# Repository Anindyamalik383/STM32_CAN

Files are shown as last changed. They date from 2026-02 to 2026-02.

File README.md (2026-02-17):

# STM32_CAN
STM32F411CEU6( Black Pill) with a CAN controller IC integrated, enabling regular CAN communications to be done.
This is done by interfacing, and a  CAN TransReceiver IC, the one used here is ATA6561-GBQW-N (Atmel IC 
PA12 and PA13 are used for interfacing with the CAN Transreceiver IC

PCB DESIGN


3D View:



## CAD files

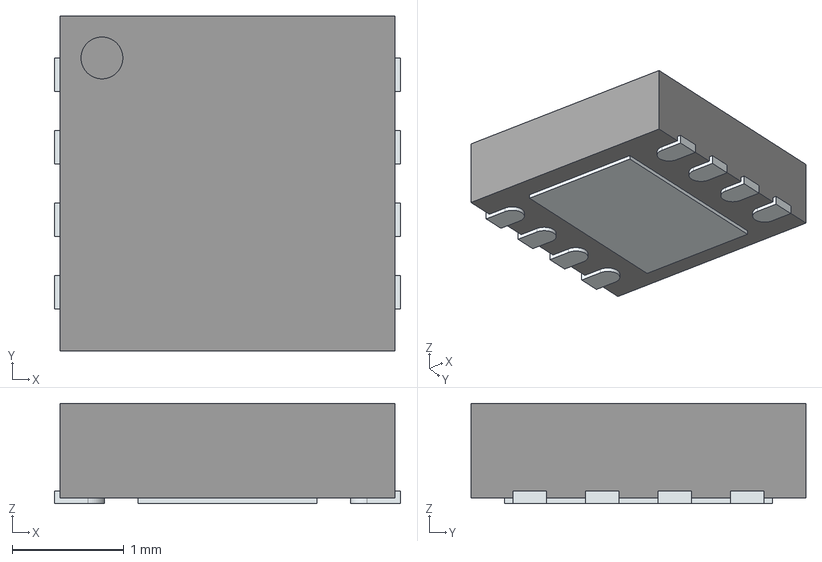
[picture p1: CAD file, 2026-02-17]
EXT_LIB/ATA6561-GBQW-N/ATA6561-GBQW-N.stp
3.10 x 3.00 x 0.9 mm
ThermalPin
PinsArrayLR

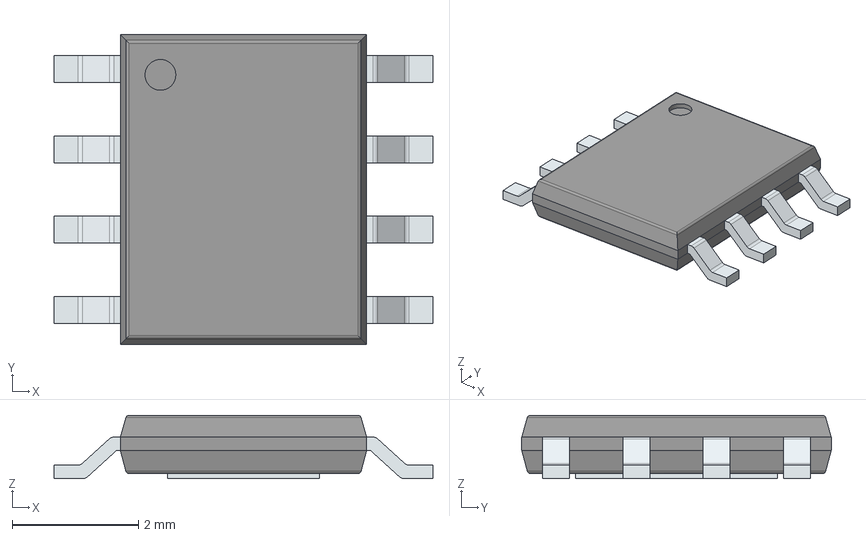
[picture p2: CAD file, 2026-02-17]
EXT_LIB/BD50GA3WEFJ-E2/3D/BD50GA3WEFJ-E2.stp
6.00 x 4.90 x 1.00 mm
PinsArrayLR
ThermalPad

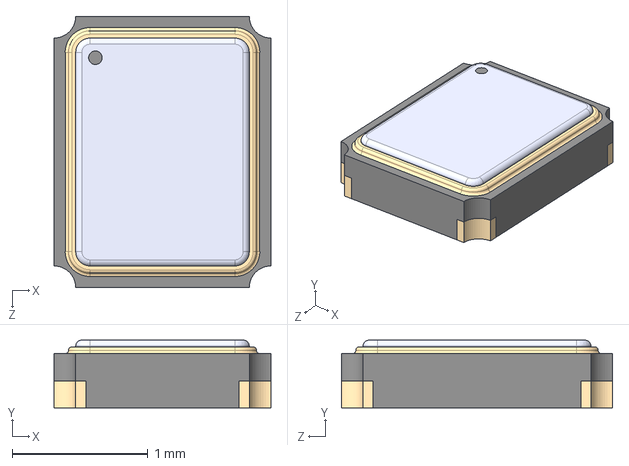
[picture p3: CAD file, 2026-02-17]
EXT_LIB/FA-128_25.0000MF10Z-AC/3D/FA-128_25.0000MF10Z-AC.stp
1.60 x 0.5 x 2.00 mm

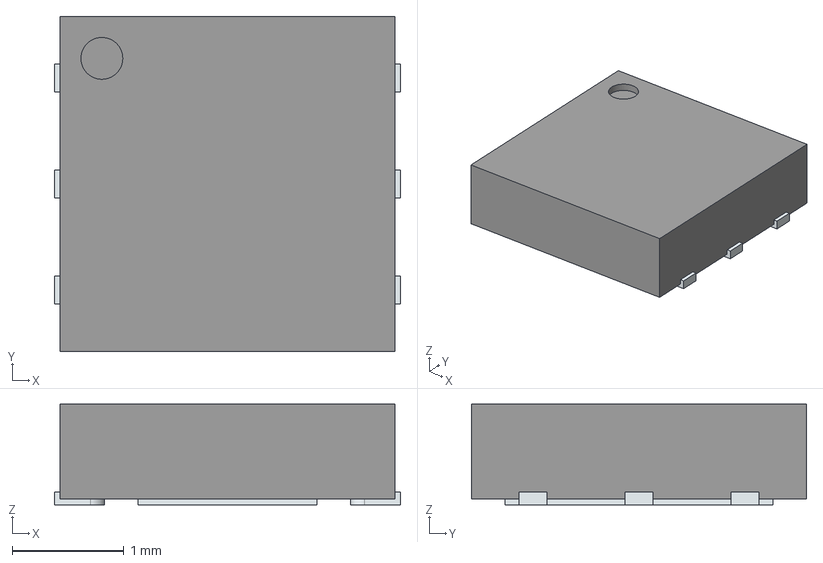
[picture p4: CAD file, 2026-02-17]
EXT_LIB/LDO40LPU33RY/3D/LDO40LPU33RY.stp
3.10 x 3.00 x 0.9 mm
ThermalPin
PinsArrayLR

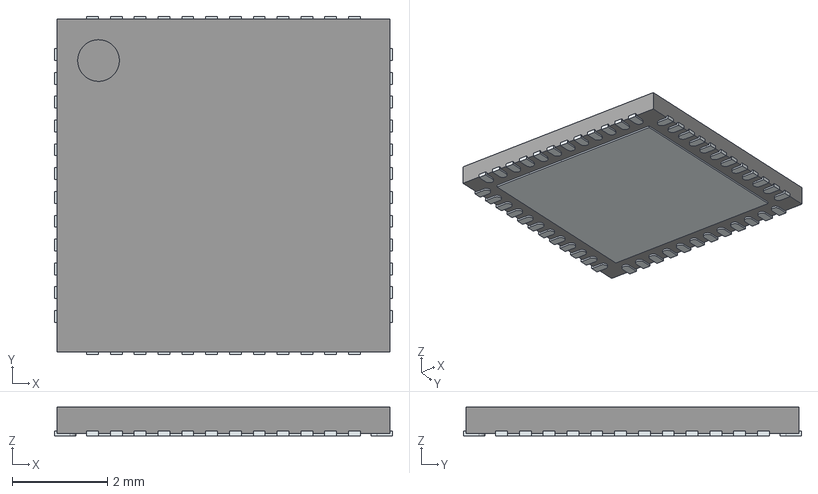
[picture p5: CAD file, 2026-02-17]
EXT_LIB/STM32F411CEU6/STM32F411CEU6.stp
7.10 x 7.10 x 0.6 mm
ThermalPin
PinsArrayLR
PinsArrayTB

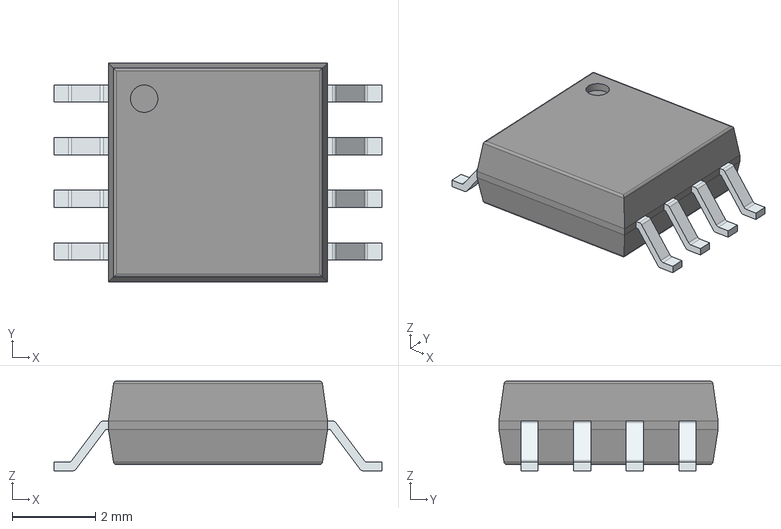
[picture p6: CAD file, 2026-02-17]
EXT_LIB/W25Q32JVSSIQ/W25Q32JVSSIQ/3D/W25Q32JVSSIQ.stp
7.90 x 5.28 x 2.16 mm
PinsArrayLR

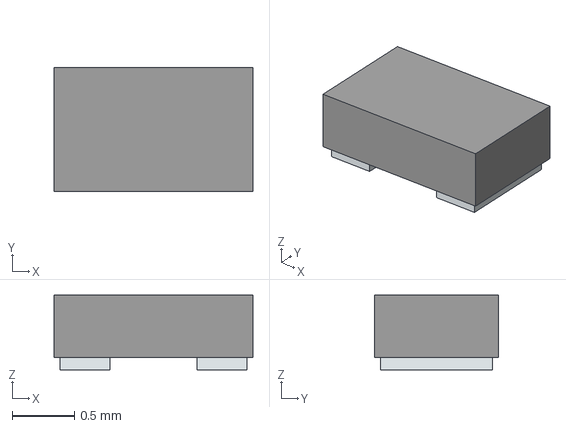
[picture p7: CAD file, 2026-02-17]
EXT_LIB/830107088501/3D/830107088501.stp
1.60 x 1.00 x 0.6 mm
Pins

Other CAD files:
EXT_LIB/W25Q32JVSSIQ/W25Q32JVSSIQ/Allegro/soic127p790x216-8n.psm
EXT_LIB/W25Q32JVSSIQ/W25Q32JVSSIQ/DEHDL/w25q32jvssiq/chips/chips.prt

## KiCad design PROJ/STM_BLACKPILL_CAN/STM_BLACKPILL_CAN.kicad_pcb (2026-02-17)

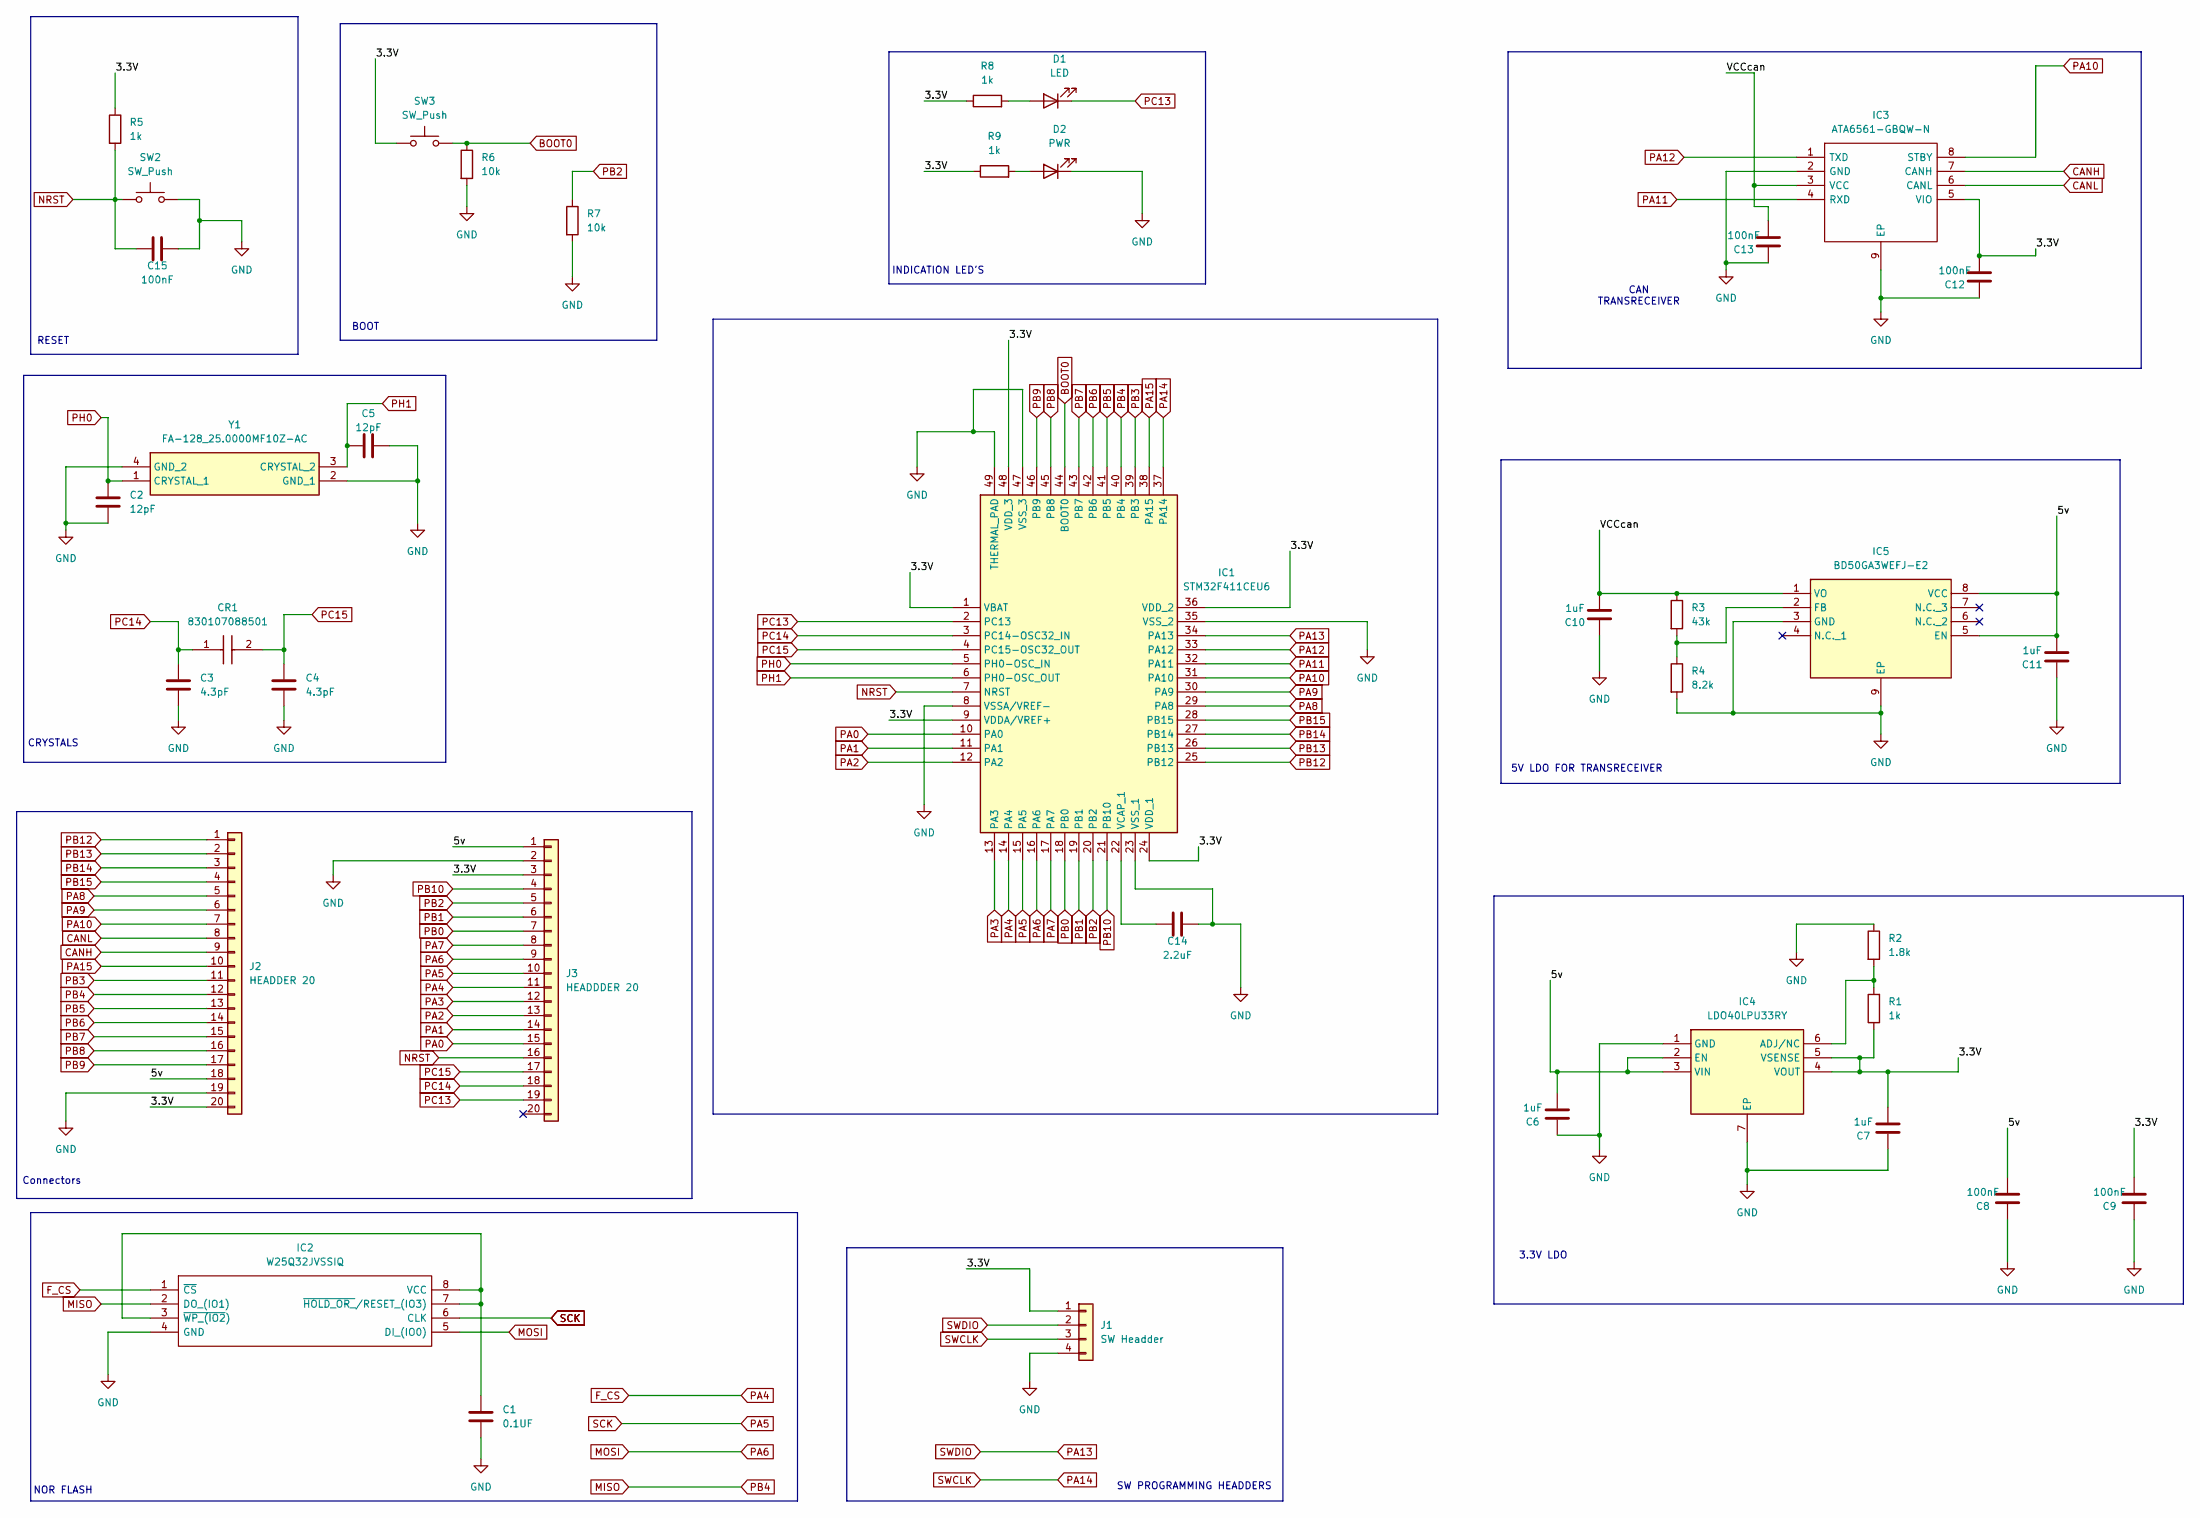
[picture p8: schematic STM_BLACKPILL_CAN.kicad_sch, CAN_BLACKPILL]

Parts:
C1: 0.1UF; C_0805_2012Metric
C2, C5: 12pF; C_0603_1608Metric
C3, C4: 4.3pF; C_0603_1608Metric
C6, C7, C10, C11: 1uF; C_0402_1005Metric
C8, C9, C12, C13, C15: 100nF; C_0603_1608Metric
C14: 2.2uF; C_0805_2012Metric
CR1: 830107088501; Mouser Part Number 710-830107088501
D1: LED; D_0201_0603Metric
D2: PWR; D_0201_0603Metric
IC1: STM32F411CEU6; QFN50P700X700X60-49N-D; Mouser Part Number 511-STM32F411CEU6
IC2: W25Q32JVSSIQ; SOIC127P790X216-8N; Mouser Part Number 454-W25Q32JVSSIQ
IC3: ATA6561-GBQW-N; SON65P300X300X90-9N-D; Mouser Part Number 579-ATA6561-GBQW-N
IC4: LDO40LPU33RY; SON95P300X300X90-7N-D; Mouser Part Number 511-LDO40LPU33RY
IC5: BD50GA3WEFJ-E2; SOIC127P600X100-9N; Mouser Part Number 755-BD50GA3WEFJ-E2
J1: SW Headder; PinHeader_1x04_P1.00mm_Vertical
J2: HEADDER 20; PinHeader_1x20_P1.00mm_Vertical
J3: HEADDDER 20; PinHeader_1x20_P1.00mm_Vertical
R1, R5, R8, R9: 1k; R_0402_1005Metric
R2: 1.8k; R_0402_1005Metric
R3: 43k; R_0603_1608Metric
R4: 8.2k; R_0402_1005Metric
R6, R7: 10k; R_1206_3216Metric
SW2, SW3: SW_Push; SW_SPST_CK_RS282G05A3
Y1: FA-128_25.0000MF10Z-AC; FA128240000MBW0; Mouser Part Number 732-FA-12825F10Z-AC

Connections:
/3.3V: C7.2, C9.2, C12.2, IC1.1 (VBAT), IC1.9 (VDDA/VREF+), IC1.24 (VDD_1), IC1.36 (VDD_2), IC1.48 (VDD_3), IC3.5 (VIO), IC4.4 (VOUT), IC4.5 (VSENSE), J1.1, J2.20, J3.3, R1.1, R5.1, R8.1, R9.1, SW3.1
/5v: C6.2, C8.2, C11.2, IC4.2 (EN), IC4.3 (VIN), IC5.5 (EN), IC5.8 (VCC), J2.18, J3.1
/VCCcan: C10.2, C13.2, IC3.3 (VCC), IC5.1 (VO), R3.1
BOOT0: IC1.44 (BOOT0), R6.1, SW3.2
CANH: IC3.7 (CANH), J2.9
CANL: IC3.6 (CANL), J2.8
F_CS: IC1.14 (PA4), IC2.1 (~CS), J3.11
GND: C1.2, C2.2, C3.2, C4.2, C5.2, C6.1, C7.1, C8.1, C9.1, C10.1, C11.1, C12.1, C13.1, C14.1, C15.1, D2.1 (K), IC1.8 (VSSA/VREF-), IC1.23 (VSS_1), IC1.35 (VSS_2), IC1.47 (VSS_3), IC1.49 (THERMAL_PAD), IC2.4 (GND), IC3.2 (GND), IC3.9 (EP), IC4.1 (GND), IC4.7 (EP), IC5.3 (GND), IC5.9 (EP), J1.4, J2.19, J3.2, R2.1, R4.2, R6.2, R7.2, SW2.2, Y1.2 (GND_1), Y1.4 (GND_2)
MISO: IC1.40 (PB4), IC2.2 (DO_(IO1)), J2.12
MOSI: IC1.16 (PA6), IC2.5 (DI_(IO0)), J3.9
NRST: C15.2, IC1.7 (NRST), J3.16, R5.2, SW2.1
unnamed: D1.2 (A), R8.2
unnamed: D2.2 (A), R9.2
unnamed: C14.2, IC1.22 (VCAP_1)
unnamed: C1.1, IC2.3 (~WP_(IO2)), IC2.7 (~HOLD_OR_/RESET_(IO3)), IC2.8 (VCC)
unnamed: IC4.6 (ADJ/NC), R1.2, R2.2
unnamed: IC5.2 (FB), R3.2, R4.1
PA0: IC1.10 (PA0), J3.15
PA1: IC1.11 (PA1), J3.14
PA2: IC1.12 (PA2), J3.13
PA3: IC1.13 (PA3), J3.12
PA5: IC1.15 (PA5), IC2.6 (CLK), J3.10
PA7: IC1.17 (PA7), J3.8
PA8: IC1.29 (PA8), J2.5
PA9: IC1.30 (PA9), J2.6
PA10: IC1.31 (PA10), IC3.8 (STBY), J2.7
PA11: IC1.32 (PA11), IC3.4 (RXD)
PA12: IC1.33 (PA12), IC3.1 (TXD)
PA13: IC1.34 (PA13), J1.2
PA14: IC1.37 (PA14), J1.3
PA15: IC1.38 (PA15), J2.10
PB0: IC1.18 (PB0), J3.7
PB1: IC1.19 (PB1), J3.6
PB2: IC1.20 (PB2), J3.5, R7.1
PB3: IC1.39 (PB3), J2.11
PB5: IC1.41 (PB5), J2.13
PB6: IC1.42 (PB6), J2.14
PB7: IC1.43 (PB7), J2.15
PB8: IC1.45 (PB8), J2.16
PB9: IC1.46 (PB9), J2.17
PB10: IC1.21 (PB10), J3.4
PB12: IC1.25 (PB12), J2.1
PB13: IC1.26 (PB13), J2.2
PB14: IC1.27 (PB14), J2.3
PB15: IC1.28 (PB15), J2.4
PC13: D1.1 (K), IC1.2 (PC13), J3.19
PC14: C3.1, CR1.1 (X1), IC1.3 (PC14-OSC32_IN), J3.18
PC15: C4.1, CR1.2 (X2), IC1.4 (PC15-OSC32_OUT), J3.17
PH0: C2.1, IC1.5 (PH0-OSC_IN), Y1.1 (CRYSTAL_1)
PH1: C5.1, IC1.6 (PH0-OSC_OUT), Y1.3 (CRYSTAL_2)

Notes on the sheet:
CRYSTALS
SW PROGRAMMING HEADDERS
NOR FLASH
5V LDO FOR TRANSRECEIVER
CAN TRANSRECEIVER
INDICATION LED'S
RESET
Connectors
3.3V LDO
BOOT

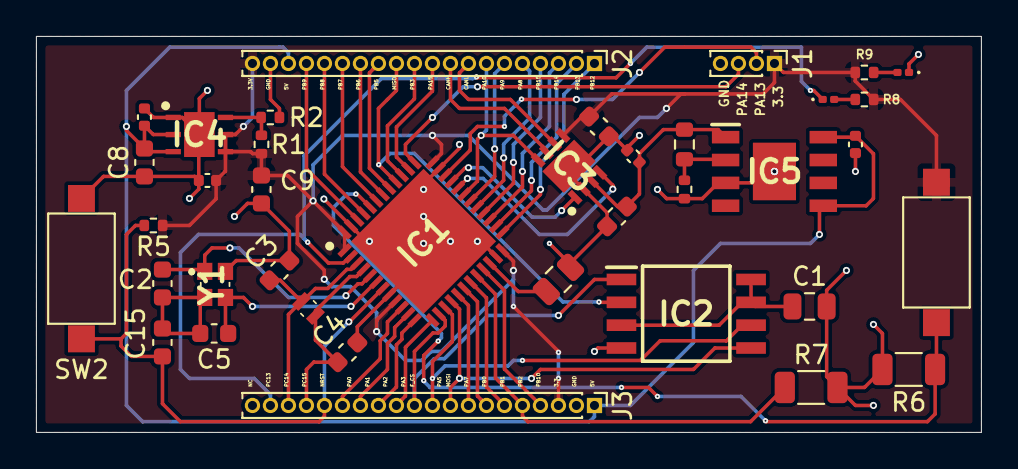
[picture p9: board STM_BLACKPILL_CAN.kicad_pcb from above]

Board: 2 copper layers, 52.5 x 22.0 mm, 38 parts (0 on the bottom side), 50 nets.

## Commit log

2026-02-17 Uploaded all project files
    [830107088501.stp, ATA6561-GBQW-N.stp, BD50GA3WEFJ-E2.stp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]
2026-02-17 Update README with PCB design and 3D view
    Added PCB design and 3D view images to README.
2026-02-17 Update README with CAN TransReceiver details
    Added details about the CAN TransReceiver IC and pin usage.
